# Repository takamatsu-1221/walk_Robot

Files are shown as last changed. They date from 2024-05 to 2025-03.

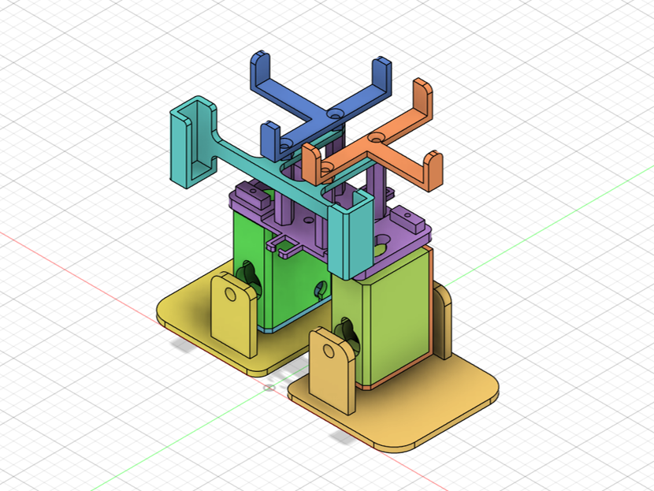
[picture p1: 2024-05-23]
Picture/CAD_front.png

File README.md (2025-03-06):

# 2足歩行ロボットの製作

## コンセプト
2足で前後左右に歩くロボットの開発

## 機構設計
筐体は3DCADソフトFusionを用いて設計を行い，3Dプリンタで出力を行った．  
4つの関節を持ち，全ての関節にサーボモータ(sg90)を用いた．  

## システム構成
マイコン構成として，RaspberryPiPico(python)とESP32(c,c++)の2台を用いる．  
RaspberryPiPicoはロボットの関節を駆動させるために用いる．  
ESP32は外部との通信，および操作画面の表示に用いる．2つのマイコンはシリアル通信を行う．  

ロボットが起動するとESP32がローカルにWebサーバを立ち上げ，スマホやPCから接続することにより操作画面を表示できる．  
操作画面は停止，前進，後退，右に進む，および左に進むの４つの選択が可能である．  
任意の操作がなされたとき，トリガが立ちシリアル通信によりRaspberryPiPicoに送信される．  
信号を受け取ると，受け取った信号に基づきロボットの関節角度が制御されロボットが動作する．  

足に貼ったQRコードを読み取ることでスマートフォン等から操作できる(同じネットワーク内に限る)．

## その他
歩行させるのもなかなか難しく，横転することもある．  


制作期間は約2.5ヶ月

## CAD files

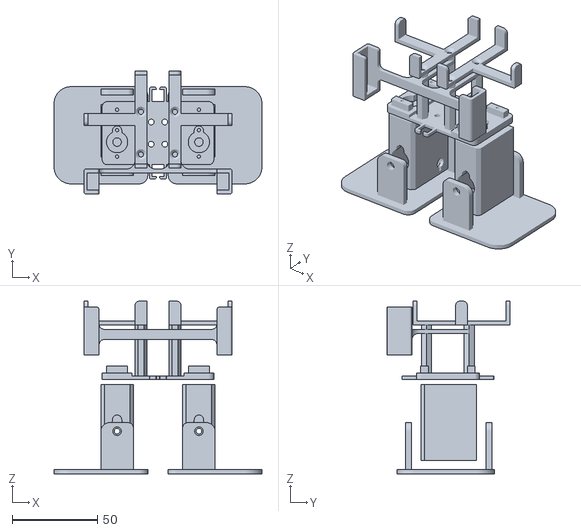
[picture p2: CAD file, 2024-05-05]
Modeling/main.stl
122.0 x 72.2 x 101.2

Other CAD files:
Modeling/main.f3z

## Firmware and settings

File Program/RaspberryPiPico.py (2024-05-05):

from machine import PWM,Pin
import time,utime

#Pin
#yellow
foot_right = PWM(Pin(0))
foot_left = PWM(Pin(1))
#green
body_right = PWM(Pin(2))
body_left = PWM(Pin(3))

#PWM signal
foot_right.freq(50)
foot_left.freq(50)
body_right.freq(50)
body_left.freq(50)

#initial degree
ini_foot_right = 90
ini_foot_left = 90
ini_body_right = 90
ini_body_left = 90

#adbance and back move
slope_twofoot = 63
slope_onefoot = 50
rotate_body = 20
delay = 0.006
delta_angle = 0.5
alfa_body = -4

#left and right move
rotate_body_side = 10
kick_angle = 40

#wait time
delay_move = 0.01
delay_action = 0.05
delay_move_side = 0.4
delay_action_side = 0.4

#move signal
do = 0

#Pin trigger
trig_reset = Pin(20, Pin.IN, Pin.PULL_DOWN)
trig_advance = Pin(19, Pin.IN, Pin.PULL_DOWN)
trig_back = Pin(18, Pin.IN, Pin.PULL_DOWN)
trig_left = Pin(17, Pin.IN, Pin.PULL_DOWN)
trig_right = Pin(16, Pin.IN, Pin.PULL_DOWN)

#Pin LED
led = Pin(25, Pin.OUT)


def main():
    led.value(1)
    reset()
    while True:
        if do==0:
            while True:
                reset()
                time.sleep(0.1)
                if do!=0:
                    break
        elif do==1:
            move_advance()
        elif do==2:
            move_back()
        elif do==3:
            move_left()
        elif do==4:
            move_right()
        print(do)
        time.sleep(0.3)
        
    
def reset():
    foot_right.duty_u16(servo_value(ini_foot_right))
    foot_left.duty_u16(servo_value(ini_foot_left))
    body_right.duty_u16(servo_value(ini_body_right))
    body_left.duty_u16(servo_value(ini_body_left))

def move_advance():
    #first action
    #foot
    servo_move(ini_foot_left, (ini_foot_left - slope_twofoot), delta_angle, delay, 1)
    servo_move(ini_foot_right, (ini_foot_right - slope_onefoot - 2), delta_angle, delay, 0)
    servo_move((ini_foot_left - slope_twofoot), ini_foot_right, delta_angle, delay, 1)
    time.sleep(delay_move)
    #body
    servo_move(ini_body_right, (ini_body_right + rotate_body + alfa_body), delta_angle, delay, 2)
    servo_move(ini_body_left, (ini_body_left + rotate_body), delta_angle, delay, 3)
    time.sleep(delay_move)
    #foot
    servo_move((ini_foot_right - slope_onefoot), ini_foot_left, delta_angle, delay, 0)
    time.sleep(delay_action)
    
    while True:
        if do!=1:
            break
        #second action
        #foot
        servo_move(ini_foot_right, (ini_foot_right + slope_twofoot), delta_angle, delay, 0)
        servo_move(ini_foot_left, (ini_foot_left + slope_onefoot), delta_angle, delay, 1)
        servo_move((ini_foot_right + slope_twofoot), ini_foot_right, delta_angle, delay, 0)
        time.sleep(delay_move)
        #body
        servo_move((ini_foot_left + rotate_body), (ini_body_left - rotate_body), delta_angle, delay, 3)
        servo_move((ini_foot_right + rotate_body + alfa_body), (ini_body_right - rotate_body - alfa_body), delta_angle, delay, 2)
        time.sleep(delay_move)
        #foot
        servo_move((ini_foot_left + slope_onefoot), ini_foot_left, delta_angle, delay, 1)
        time.sleep(delay_action)
        
        if do!=1:
            break
        #third action
        #foot
        servo_move(ini_foot_left, (ini_foot_left - slope_twofoot), delta_angle, delay, 1)
        servo_move(ini_foot_right, (ini_foot_right - slope_onefoot), delta_angle, delay, 0)
        servo_move((ini_foot_left - slope_twofoot), ini_foot_left, delta_angle, delay, 1)
        time.sleep(delay_move)
        #body
        servo_move((ini_foot_right - rotate_body - alfa_body), (ini_body_right + rotate_body + alfa_body), delta_angle, delay, 2)
        servo_move((ini_foot_left - rotate_body), (ini_body_left + rotate_body), delta_angle, delay, 3)
        time.sleep(delay_move)
        #foot
        servo_move((ini_foot_right - slope_onefoot), ini_foot_right, delta_angle, delay, 0)
        time.sleep(delay_action)
        
    reset()
    
        
def move_back():    
    #first action
    #foot
    servo_move(ini_foot_left, (ini_foot_left - slope_twofoot), delta_angle, delay, 1)
    servo_move(ini_foot_right, (ini_foot_right - slope_onefoot), delta_angle, delay, 0)
    servo_move((ini_foot_left - slope_twofoot), ini_foot_right, delta_angle, delay, 1)
    time.sleep(delay_move)
    #body
    servo_move(ini_body_right, (ini_body_right - rotate_body + alfa_body), delta_angle, delay, 2)
    servo_move(ini_body_left, (ini_body_left - rotate_body), delta_angle, delay, 3)
    time.sleep(delay_move)
    #foot
    servo_move((ini_foot_right - slope_onefoot), ini_foot_left, delta_angle, delay, 0)
    time.sleep(delay_action)
    
    while True:
        if do!=2:
            break
        #second action
        #foot
        servo_move(ini_foot_right, (ini_foot_right + slope_twofoot), delta_angle, delay, 0)
        servo_move(ini_foot_left, (ini_foot_left + slope_onefoot), delta_angle, delay, 1)
        servo_move((ini_foot_right + slope_twofoot), ini_foot_right, delta_angle, delay, 0)
        time.sleep(delay_move)
        #body
        servo_move((ini_foot_left - rotate_body), (ini_body_left + rotate_body), delta_angle, delay, 3)
        servo_move((ini_foot_right - rotate_body + alfa_body), (ini_body_right + rotate_body - alfa_body), delta_angle, delay, 2)
        time.sleep(delay_move)
        #foot
        servo_move((ini_foot_left + slope_onefoot), ini_foot_left, delta_angle, delay, 1)
        time.sleep(delay_action)
        
        if do!=2:
            break
        #third action
        #foot
        servo_move(ini_foot_left, (ini_foot_left - slope_twofoot), delta_angle, delay, 1)
        servo_move(ini_foot_right, (ini_foot_right - slope_onefoot), delta_angle, delay, 0)
        servo_move((ini_foot_left - slope_twofoot), ini_foot_left, delta_angle, delay, 1)
        time.sleep(delay_move)
        #body
        servo_move((ini_foot_right + rotate_body - alfa_body), (ini_body_right - rotate_body + alfa_body), delta_angle, delay, 2)
        servo_move((ini_foot_left + rotate_body), (ini_body_left - rotate_body), delta_angle, delay, 3)
        time.sleep(delay_move)
        #foot
        servo_move((ini_foot_right - slope_onefoot), ini_foot_right, delta_angle, delay, 0)
        time.sleep(delay_action)
        
    reset()
        


def move_left():
    body_right.duty_u16(servo_value(ini_body_right - 10))
    body_left.duty_u16(servo_value(ini_body_left - 10))
    
    while True:
        foot_left.duty_u16(servo_value(ini_foot_left + kick_angle))
        time.sleep(0.15)
        foot_right.duty_u16(servo_value(ini_foot_right - kick_angle))
        foot_left.duty_u16(servo_value(ini_foot_left - kick_angle))
        time.sleep(delay_action_side)
        
        foot_right.duty_u16(servo_value(ini_foot_right))
        foot_left.duty_u16(servo_value(ini_foot_left))
        time.sleep(delay_move_side)
        
        if do!=3:
            break
    
    reset()
    
def move_right():
    body_left.duty_u16(servo_value(ini_body_left + rotate_body_side))
    body_right.duty_u16(servo_value(ini_body_right - rotate_body_side))
    
    while True:
        foot_right.duty_u16(servo_value(ini_foot_right - kick_angle))
        time.sleep(0.1)
        foot_left.duty_u16(servo_value(ini_foot_left + kick_angle))
        foot_right.duty_u16(servo_value(ini_foot_right + kick_angle))
        time.sleep(delay_action_side)
        
        foot_left.duty_u16(servo_value(ini_foot_right))
        foot_right.duty_u16(servo_value(ini_foot_right))
        time.sleep(delay_move_side)
        
        if do!=4:
            break
    
    reset()
    


    
#Move servo function
#servo_move(start, target, delta, delay, pin)
def servo_move(current, target, delta, time, pin):
    servo = PWM(Pin(pin))
    servo.freq(50)
    if current < target:
        while current < target:
            servo.duty_u16(servo_value(current))
            current += delta
            utime.sleep(time)
    else:
        while target < current:
            servo.duty_u16(servo_value(current))
            current -= delta
            utime.sleep(time)


def servo_value(degree):
    return int((degree * 9.5 / 180 + 2.5) * 65535 / 100)


#robot control system
def signal_reset(p):
    global do
    do = 0
    
def signal_advance(p):
    global do
    do = 1
    
def signal_back(p):
    global do
    do = 2
    
def signal_left(p):
    global do
    do = 3

def signal_right(p):
    global do
    do = 4

    
trig_reset.irq(trigger=Pin.IRQ_RISING, handler=signal_reset)
trig_advance.irq(trigger=Pin.IRQ_RISING, handler=signal_advance)
trig_back.irq(trigger=Pin.IRQ_RISING, handler=signal_back)
trig_left.irq(trigger=Pin.IRQ_RISING, handler=signal_left)
trig_right.irq(trigger=Pin.IRQ_RISING, handler=signal_right)


if __name__=="__main__":
    main()

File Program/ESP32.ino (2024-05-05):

#include <WiFi.h>
#include <WebServer.h>
#include <Wire.h>
#include "SSD1306.h"

//Wifi SSID,Password
const char* ssid     = "";
const char* password = "";

//WebServer begin
WebServer server(80);

//Pin
const int trig_reset = 0;
const int trig_advance = 4;
const int trig_back = 16;
const int trig_left = 17;
const int trig_right = 5;

//display
SSD1306  display(0x3c, 21, 22);


void setup() {
  display.init();
  display.setFont(ArialMT_Plain_24);
  display.drawString(0, 16, "connecting...");
  display.display();
  
  //Pin asign
  pinMode(trig_reset, OUTPUT);
  pinMode(trig_advance, OUTPUT);
  pinMode(trig_back, OUTPUT);
  pinMode(trig_left, OUTPUT);
  pinMode(trig_right, OUTPUT);
  //Initial signal
  digitalWrite(trig_reset, LOW);
  digitalWrite(trig_advance, LOW);
  digitalWrite(trig_back, LOW);
  digitalWrite(trig_left, LOW);
  digitalWrite(trig_right, LOW);
  
  WiFi.begin(ssid, password);
  while (WiFi.status() != WL_CONNECTED) {
    delay(300);
  }

  //display output
  display.init();
  display.setFont(ArialMT_Plain_24);
  display.drawString(40, 16, out_ip(WiFi.localIP()));
  display.display();

  //server started
  server.on("/", move_mainpage);
  server.onNotFound(handleNotFound);
  server.begin();
}


void loop() {
  server.handleClient();
}



//main page
void move_mainpage() {
  String html;
  //HTML
  html = "<!DOCTYPE html>";
  html += "<html lang='ja'>";
  html += "<head>";
  html += "<meta charset=\"utf-8\">";
  html += "<title>Robot move system</title>";
  html += "</head>";
  
  html += "<body>";
  
  html += "<center>";
  html += "<h1>welcome to robot control system!</h1>";
  html += "</center>";

  html += "<br>";

  html += "<center>";
  html += "<p>";
  html += "<a href=\"/?advance=on\">↑advance↑</a>";
  html += "</p>";
  html += "</center>";

  html += "<center>";
  html += "<p>";
  html += "<a href=\"/?left=on\">←left</a>";
  html += "</p>";
  html += "</center>";

  html += "<center>";
  html += "<p>";
  html += "<a href=\"/?right=on\">right→</a>";
  html += "</p>";
  html += "</center>";

  html += "<center>";
  html += "<p>";
  html += "<a href=\"/?back=on\">↓back↓</a>";
  html += "</p>";
  html += "</center>";

  html += "<br>";

  html += "<center>";
  html += "<p>";
  html += "<a href=\"/?reset=on\">reset & stop</a>";
  html += "</p>";
  html += "</center>";

  html += "</body>";
  html += "</html>";

  //click active
  if (server.hasArg("reset")){
    if (server.arg("reset").equals("on")){
      digitalWrite(trig_reset, HIGH);
      digitalWrite(trig_advance, LOW);
      digitalWrite(trig_back, LOW);
      digitalWrite(trig_left, LOW);
      digitalWrite(trig_right, LOW);
    }
  }
  
  else if (server.hasArg("advance")){
    if (server.arg("advance").equals("on")){
      digitalWrite(trig_reset, LOW);
      digitalWrite(trig_advance, HIGH);
      digitalWrite(trig_back, LOW);
      digitalWrite(trig_left, LOW);
      digitalWrite(trig_right, LOW);
    }
  }

  else if (server.hasArg("back")){
    if (server.arg("back").equals("on")){
      digitalWrite(trig_reset, LOW);
      digitalWrite(trig_advance, LOW);
      digitalWrite(trig_back, HIGH);
      digitalWrite(trig_left, LOW);
      digitalWrite(trig_right, LOW);
    }
  }

  else if (server.hasArg("left")){
    if (server.arg("left").equals("on")){
      digitalWrite(trig_reset, LOW);
      digitalWrite(trig_advance, LOW);
      digitalWrite(trig_back, LOW);
      digitalWrite(trig_left, HIGH);
      digitalWrite(trig_right, LOW);
    }
  }

  else if (server.hasArg("right")){
    if (server.arg("right").equals("on")){
      digitalWrite(trig_reset, LOW);
      digitalWrite(trig_advance, LOW);
      digitalWrite(trig_back, LOW);
      digitalWrite(trig_left, LOW);
      digitalWrite(trig_right, HIGH);
    }
  }
  
  server.send(200, "text/html", html);
}



//ip_adress to string
String out_ip(uint32_t ip){
    String result = "";
    result += String((ip & 0xFF), 10);
    result += ".";
    result += String((ip & 0xFF00) >> 8, 10);
    result = "";
    result += ".";
    result += String((ip & 0xFF0000) >> 16, 10);
    result += ".";
    result += String((ip & 0xFF000000) >> 24, 10);
    return result;
}

//Not found
void handleNotFound(void) {
  server.send(404, "text/plain", "Not Found");
}
